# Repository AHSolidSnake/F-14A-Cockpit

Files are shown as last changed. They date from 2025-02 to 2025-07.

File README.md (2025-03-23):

# F-14A-Cockpit
All the STL files for 3D printing a VR focussed F-14A Tomcat cockpit.

Disclaimer: This is designed to work as an artistic license version of a Tomcat which looks "about right" from a few feet away, and feels close enough while playing with a VR headset that the controls are where you reach for them. These files are provided for free to do what you like with and generally if they are uploaded then I have printed them at least once, but YMMV.

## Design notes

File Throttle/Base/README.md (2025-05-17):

# Throttle Base

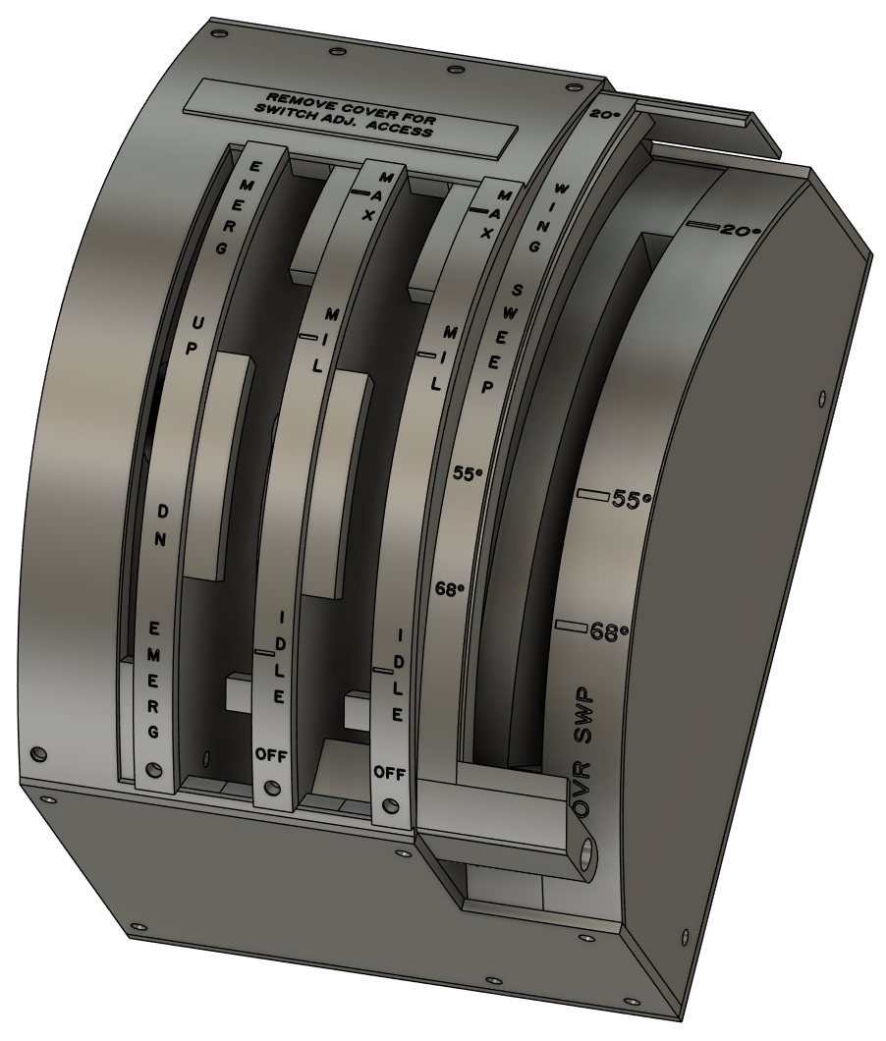
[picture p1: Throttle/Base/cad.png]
CAD Example


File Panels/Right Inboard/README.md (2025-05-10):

# Right Inboard 

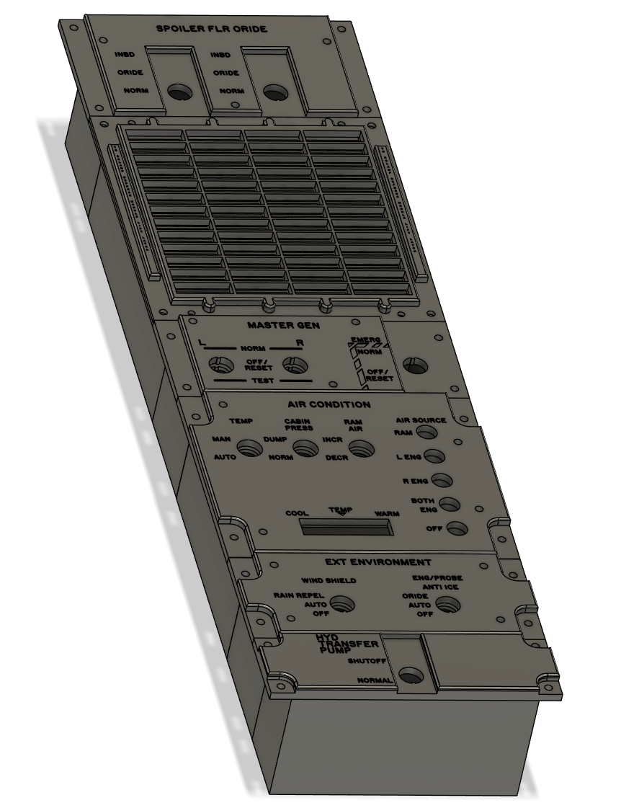
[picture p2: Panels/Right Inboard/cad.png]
CAD Example


## BoM

### Spoiler Override

- 12mm Toggle On-Off x1 [T8013](https://www.aliexpress.com/item/1005001315963290.html)
- Switch Cover [RED](https://www.aliexpress.com/item/1005006832895893.html)

### Caution and Warning

- 4mm LED holders x45 
- Yellow LED x35
- Green LED x10 
- 130mm x 123mm 2mm clear acrylic

### Master Generator

- 12mm Toggle On-Off-On x2 [T8014](https://www.aliexpress.com/item/1005001315963290.html)
- 12mm Toggle On-Off x1 [T8013](https://www.aliexpress.com/item/1005001315963290.html)

### Air Condition

- 12mm Toggle On-Off x3 [T8013](https://www.aliexpress.com/item/1005001315963290.html)
- Piano Switches - Credit to user Hagen at DCS Forums [LINK](https://forum.dcs.world/topic/141193-f-14-cockpit-and-instrument-dimensions/page/38/)

### External Environment

- 12mm Toggle On-Off-On x2 [T8014](https://www.aliexpress.com/item/1005001315963290.html)

### Hydraulic Transfer Pump

- 12mm Toggle On-Off x1 [T8013](https://www.aliexpress.com/item/1005001315963290.html)
- Switch Cover [RED](https://www.aliexpress.com/item/1005006832895893.html)

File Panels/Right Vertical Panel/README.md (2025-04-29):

# Right Vertical Panel

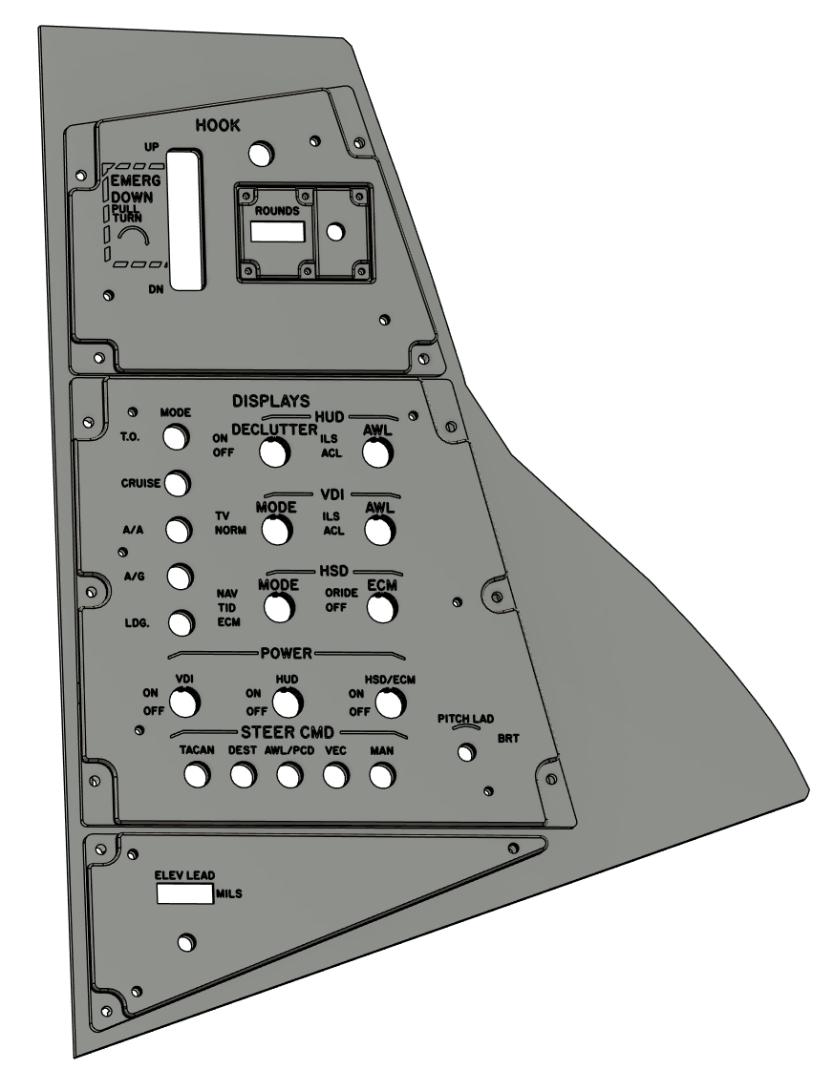
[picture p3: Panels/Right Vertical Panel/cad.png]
CAD Example


## BoM

### Hook Panel

- Rotary Encoder
- 2mm clear acrylic window 24mm x 11mm
- Hook Lever - [Tek Creations F-18 Mk3](https://tekcreations.space/product/f18-hornet-hook-lever-mkii/)

### PDCP

- 12mm Toggle On-Off x9 [T8013](https://www.aliexpress.com/item/1005001315963290.html)
- Piano Switches - Credit to user Hagen at DCS Forums [LINK](https://forum.dcs.world/topic/141193-f-14-cockpit-and-instrument-dimensions/page/38/)
- Rotary Encoder

### Gun Elevation

- Rotary Encoder
- Tally Counter (Non functional) [LINK](https://amzn.eu/d/he2qN3s)
- 2mm clear acrylic window 25mm x 11mm

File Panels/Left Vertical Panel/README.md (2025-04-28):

# Left Vertical Panel

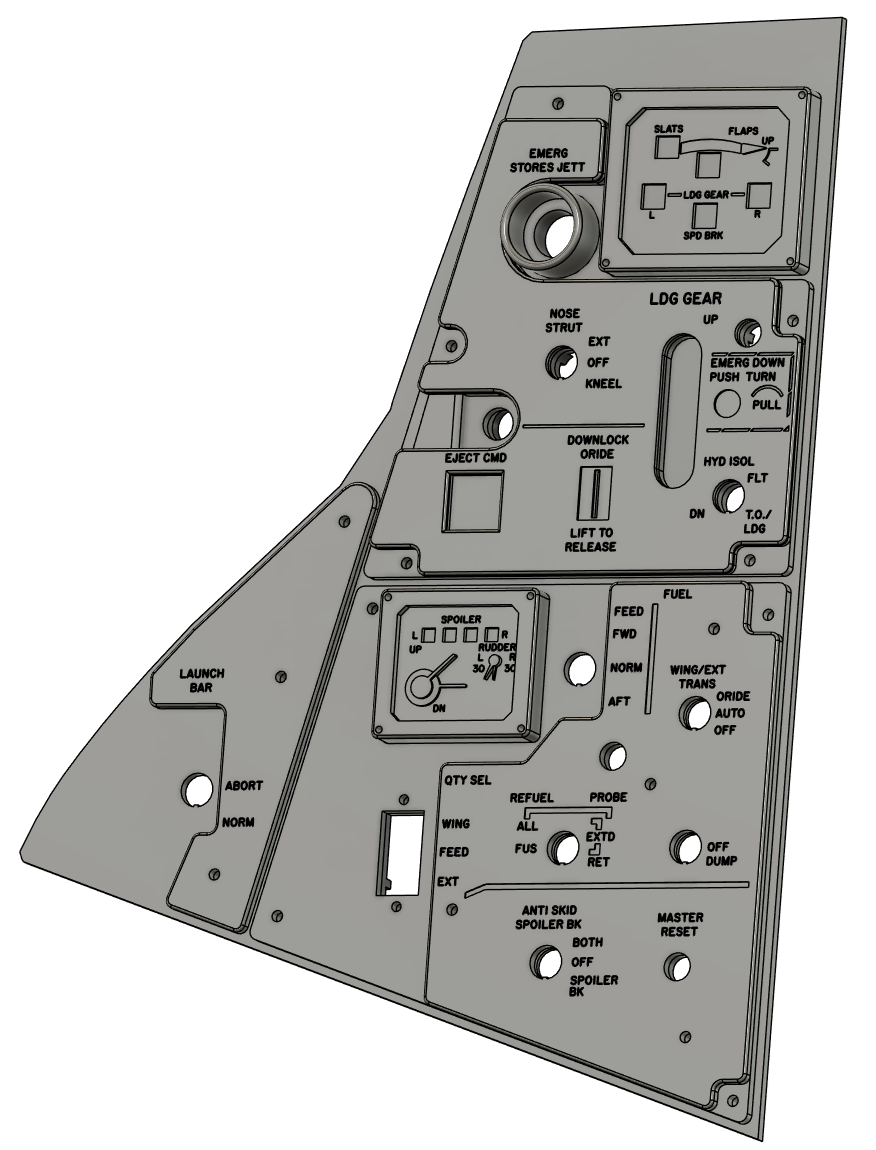
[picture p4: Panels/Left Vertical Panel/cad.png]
CAD Example


Trim and Gear panels are non-functional and for display purposes only.

## BoM

### Gear Panel

- Emergency JETT - 16mm red push button [LINK](https://amzn.eu/d/eFpsVKk)

- Brakes - 10mm Push Pull Switch [LINK](https://www.aliexpress.com/item/1005007343801175.html)

- Gear Lever - [Tek Creations F-18 Mk3](https://tekcreations.space/product/f18-hornet-hook-lever-mkii/)

### Fuel Panel

- Master Reset - 12mm Push Button Switch [R13-85](https://www.aliexpress.com/item/1042107033.html)

- Fuel Trans, Refuel, Spoiler Brakes - 3x On-Off-On 12mm Toggle [T8014](https://www.aliexpress.com/item/1005001315963290.html)

- Fuel Dump - On-Off 12mm Toggle  [T8013](https://www.aliexpress.com/item/1005001315963290.html)

- Quantity Switch - (On) Off (On) Rocker [NKK SW-3007A](https://www.aliexpress.com/item/1005008354400323.html)

### Launch Bar

- Launch Abort - On-Off 12mm Toggle  [T8013](https://www.aliexpress.com/item/1005001315963290.html)

- Launch Abort Cover - [LINK](https://www.aliexpress.com/item/1005006832895893.html)

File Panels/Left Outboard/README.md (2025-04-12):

# Left Outboard

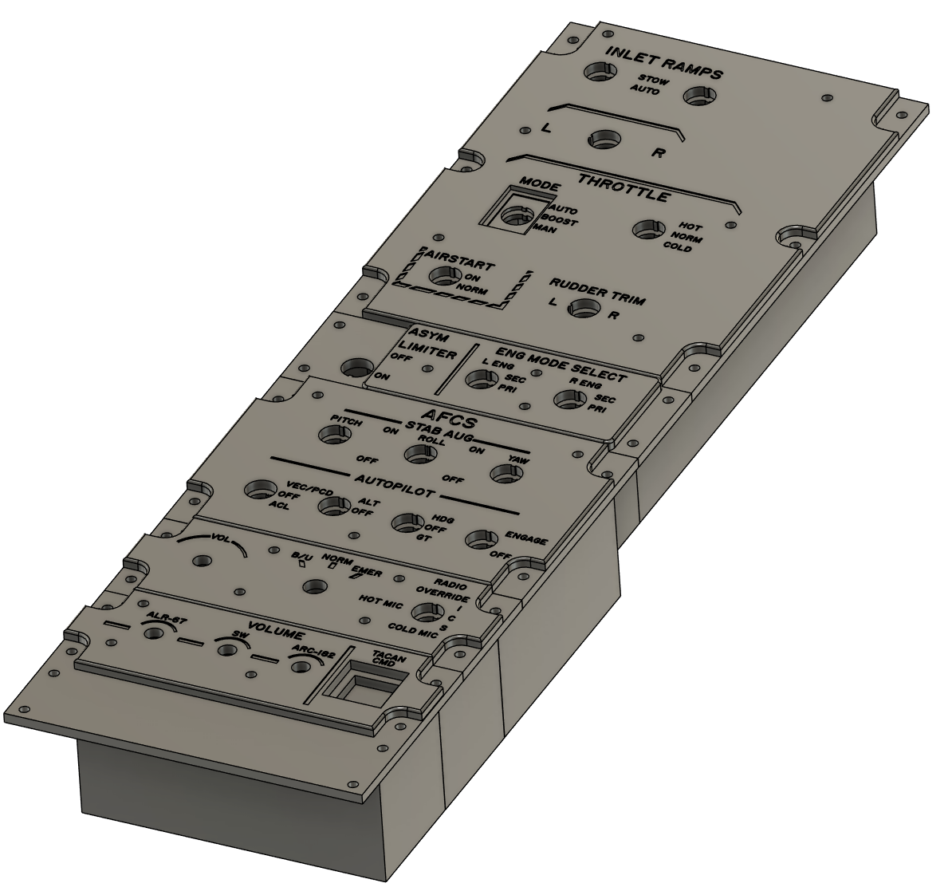
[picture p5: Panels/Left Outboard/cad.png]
CAD Example


## BoM

### Throttle

- 12mm Toggle On-Off x3 [T8013](https://www.aliexpress.com/item/1005001315963290.html)
- 12mm Toggle On-Off-On x2 [T8014](https://www.aliexpress.com/item/1005001315963290.html)
- 12mm Toggle (On)-Off-(On) 

### Engine Asymmetric Limiter 

- 12mm Toggle On-Off x3 [T8013](https://www.aliexpress.com/item/1005001315963290.html)
- Switch Cover [RED](https://www.aliexpress.com/item/1005006832895893.html)

### AFCS

- 12mm Toggle On-Off x5 [T8013](https://www.aliexpress.com/item/1005001315963290.html)
- 12mm Toggle On-Off-On x2 [T8014](https://www.aliexpress.com/item/1005001315963290.html)

### ICS

- 12mm Toggle On-Off-On x1 [T8014](https://www.aliexpress.com/item/1005001315963290.html)
- 3 Way Rotary
- Potentiometer

### Volumes

- 3x Potentiometer 
- Lit Square Korry Style Switche x 1 [DIY737](https://www.737diysim.com/product-page/custom-dual-colour-korry-replica)

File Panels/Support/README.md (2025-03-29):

# Structure

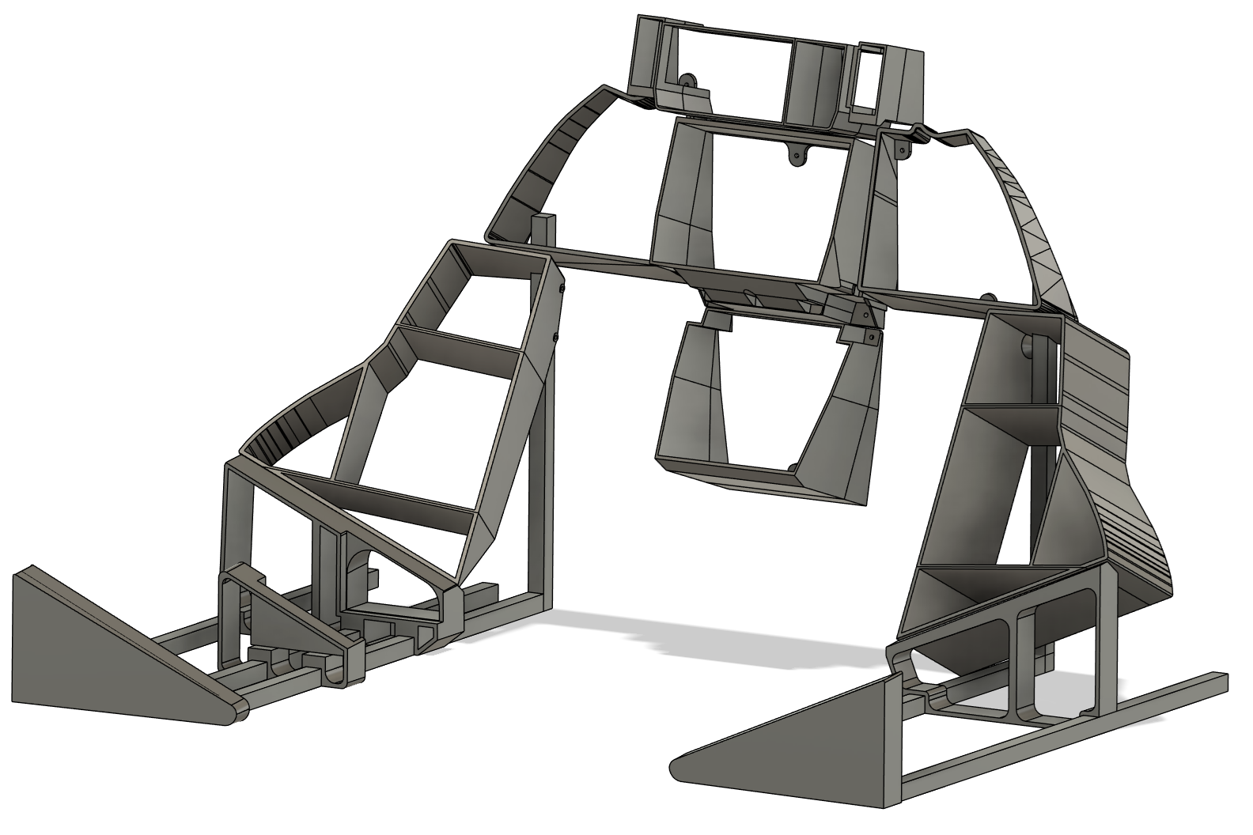
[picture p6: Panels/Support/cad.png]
CAD Example


## BoM

- 20x20 Aluminium Extrusion

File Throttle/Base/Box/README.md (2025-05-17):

# Box / Outer Case

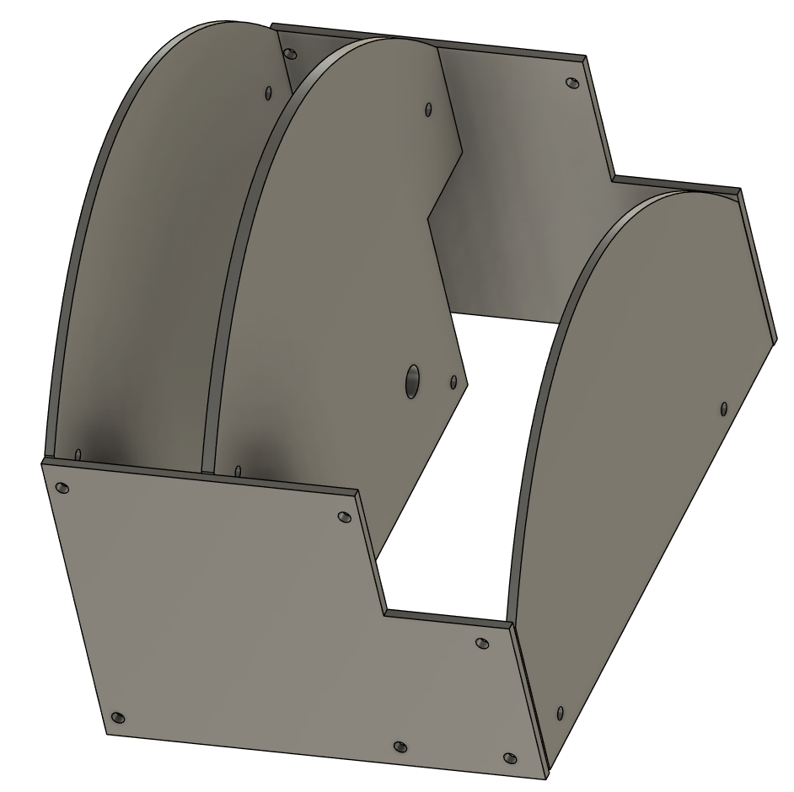
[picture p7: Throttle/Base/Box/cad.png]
CAD Example


Either 3D print STL files or laser cut acrylic/aluminium to build casing.

Back/Front/Left/Right 	- 3mm thickness
Center 			- 4mm thickness

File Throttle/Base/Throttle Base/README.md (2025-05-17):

# Throttle Base

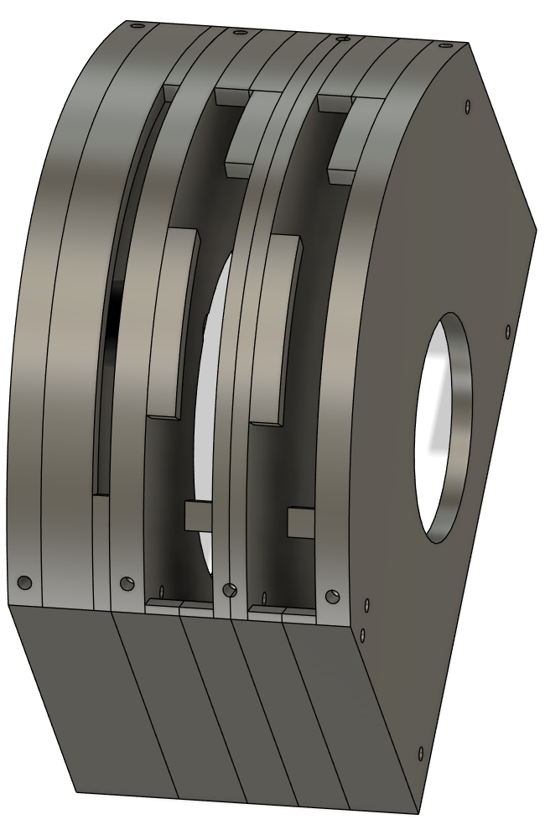
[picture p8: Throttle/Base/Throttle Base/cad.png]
CAD Example


From left to right

- (Box/Left Plate)
- Flaps Box
- Throttle Levers Left Plate
- Throttle Levers Middle Left
- (Box/Center Plate)
- Throttle Levers Middle Right
- Throttle Levers Right Plate
- (Wingsweep)

## BoM

- 2x Rotary Damper in Left/Right Plates [ACE Controls FDT-70](https://www.acecontrols.co.uk/uk/products/motion-control/rotary-dampers/fdt/fdt/fdt-70.html)

- 2x Hall Effect Potentiometer in Center Plate [TT6127](https://www.ttelectronics.com/Products/Passive-Components/Potentiometers/6127)

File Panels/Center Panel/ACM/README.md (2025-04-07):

# ACM Panel

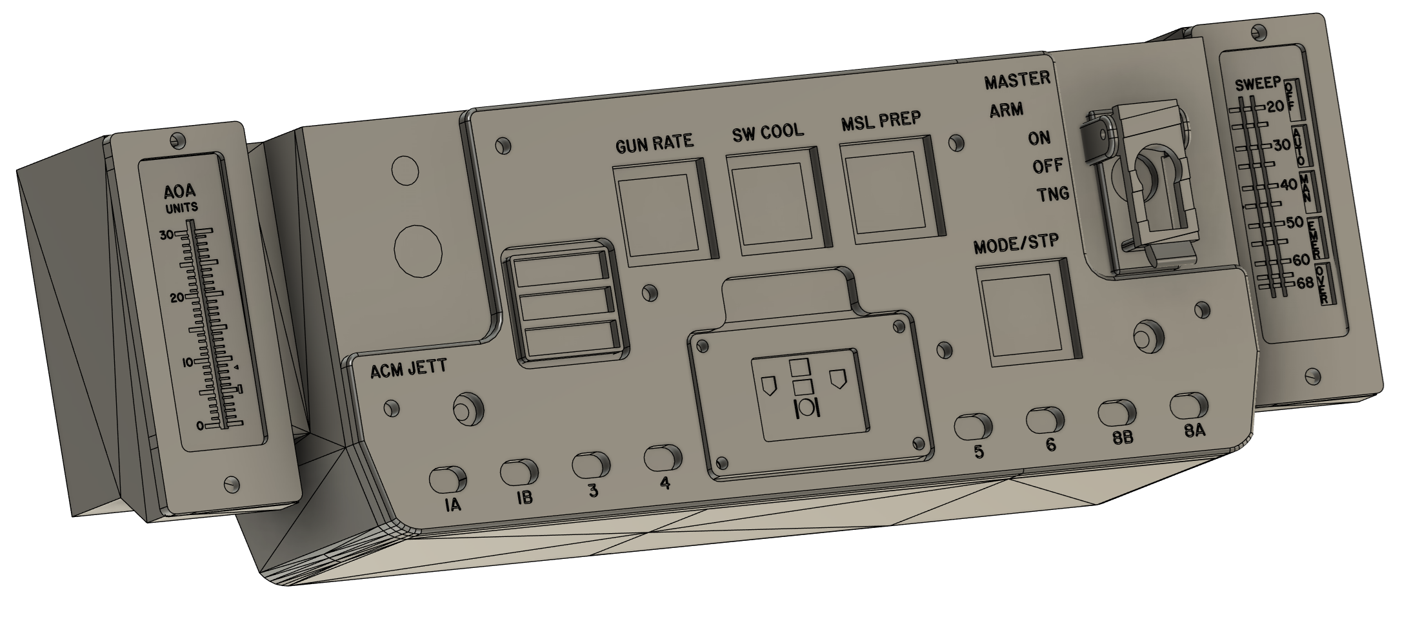
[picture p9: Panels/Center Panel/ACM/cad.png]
CAD Example


AoA / Wing Sweep / Turn-Slip Indicator are non-functional and for display purposes only.

## BoM

- Master Arm - 12mm Locking Toggle Switch [NKK S-7AL](https://www.aliexpress.com/item/1005007970489843.html)

- Lit Square Korry Style Switches x 4 [DIY737](https://www.737diysim.com/product-page/custom-dual-colour-korry-replica)

- ACM JETT - 12mm Push Button Switch [R13-85](https://www.aliexpress.com/item/1042107033.html)

- ACM JETT - Mini Toggle

- ACM JETT Cover - LA Sooner Shapeways (No Link)

- 71mm x 24mm Clear Acrylic Window AoA/Wing Sweep

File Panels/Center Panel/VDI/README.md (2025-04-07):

# VDI

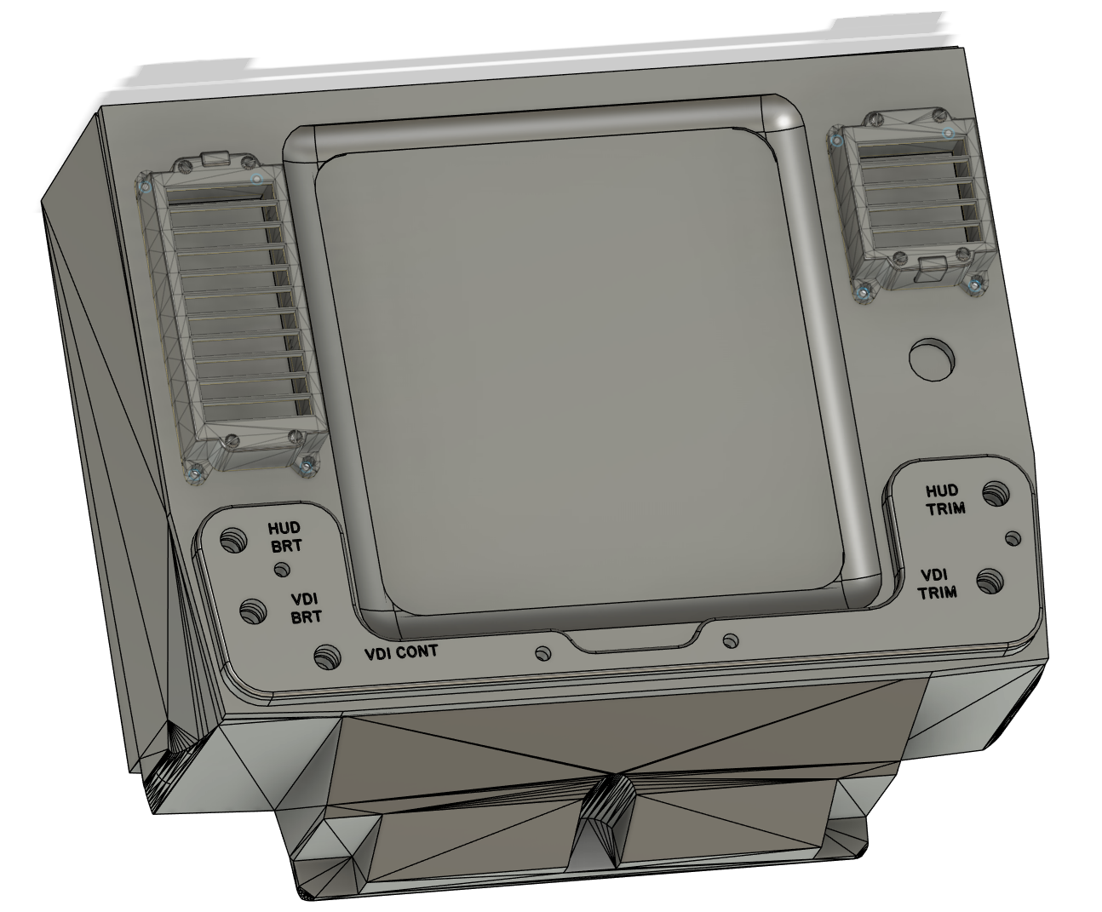
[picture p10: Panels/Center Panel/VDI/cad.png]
CAD Example


## BoM

- Filter - Push Pull Switch [LINK](https://www.aliexpress.com/item/1005007343801175.html?spm=a2g0o.order_list.order_list_main.10.4b8e1802ASbqHO)

- Long 13mm Potentiometers [LINK](https://amzn.eu/d/cVvK1kD)

- 17mm Potentiometer Knobs [LINK](https://amzn.eu/d/1eI4sv0)

- 8" Screen [LINK](https://www.aliexpress.com/item/1005007225502307.html)

- 144mm x 138mm Tinted Acrylic

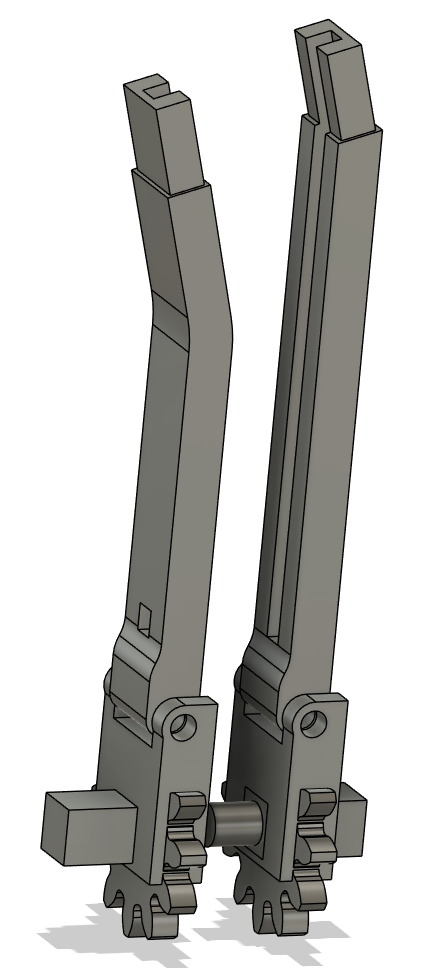
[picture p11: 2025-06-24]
Throttle/Grips/Levers/cad.png

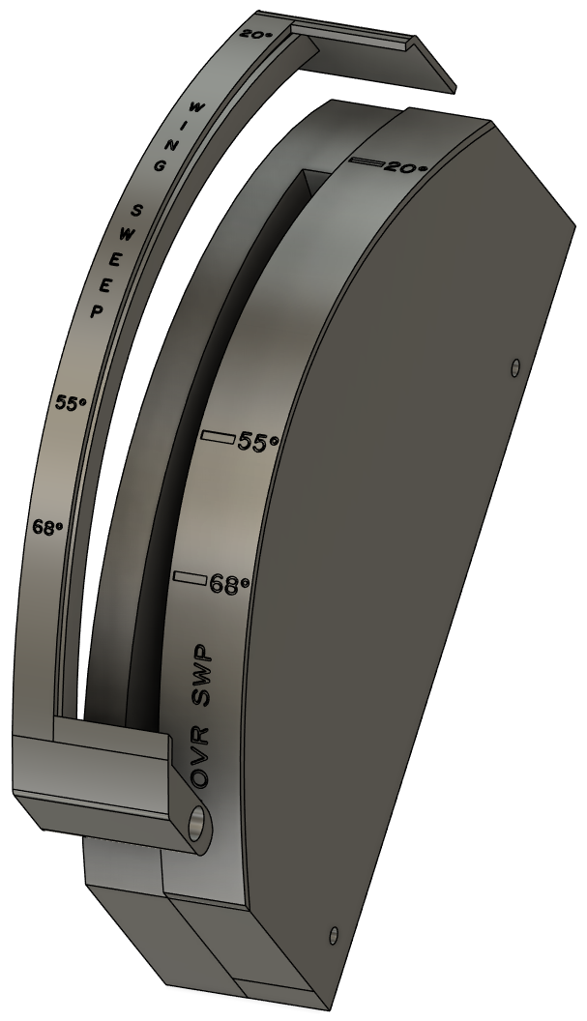
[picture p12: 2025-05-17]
Throttle/Base/Wing Sweep/cad.png

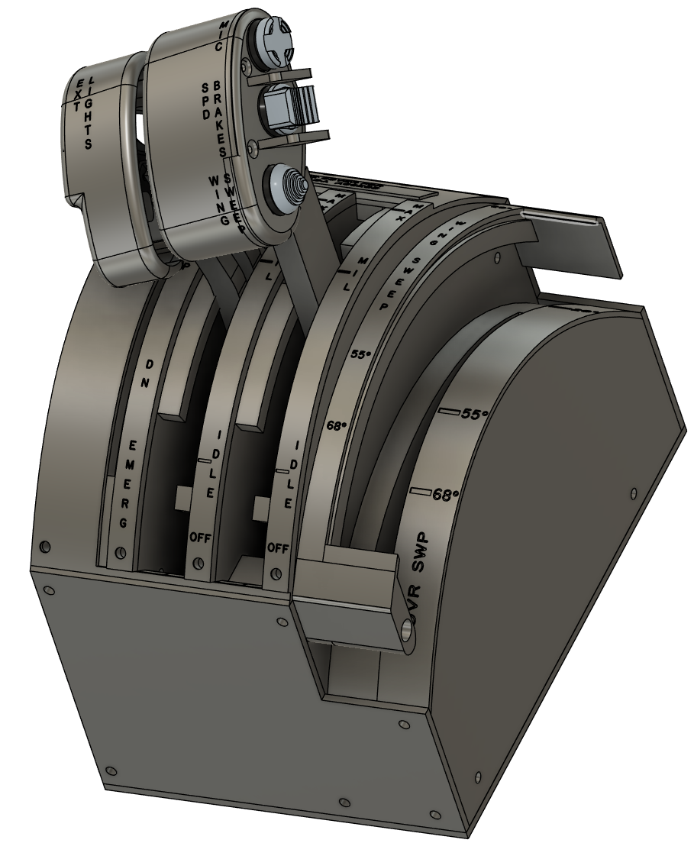
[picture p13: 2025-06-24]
Throttle/cad.png

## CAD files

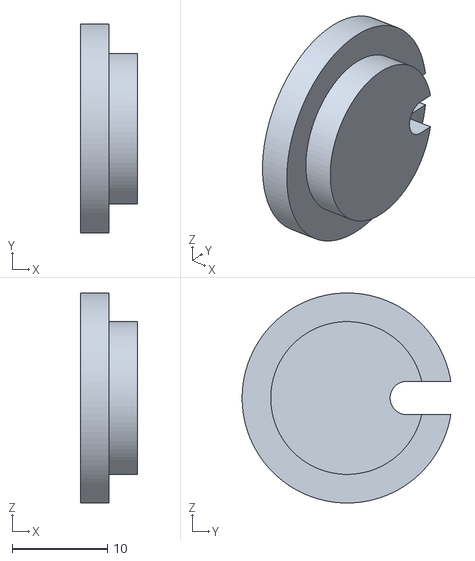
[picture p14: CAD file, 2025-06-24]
Extras/16mm USB Plug x1.stl
6.00 x 21.9 x 22.0

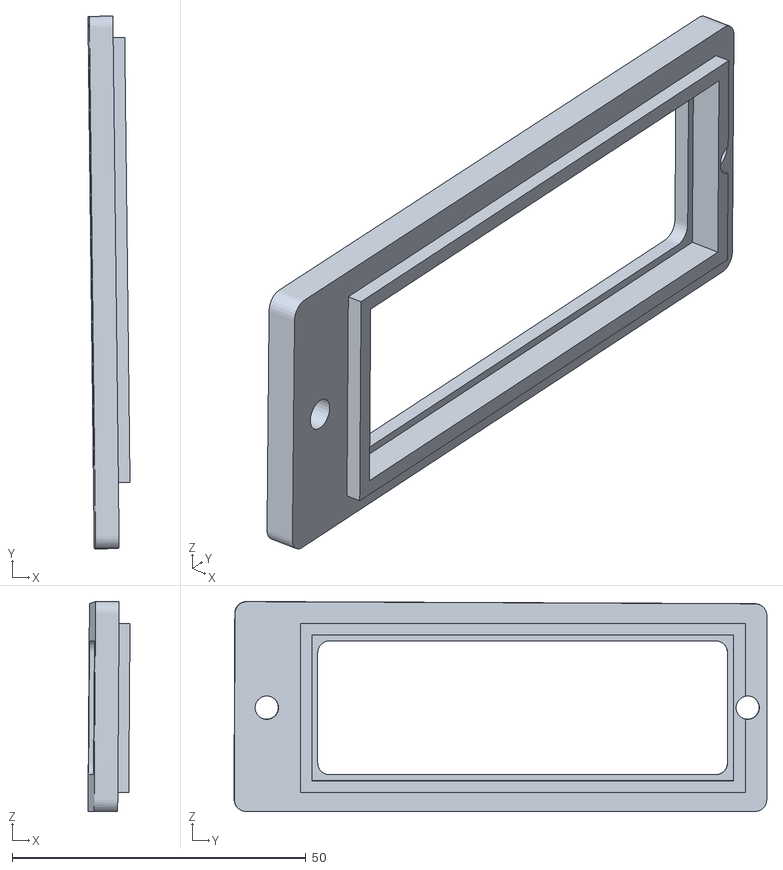
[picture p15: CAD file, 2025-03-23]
Panels/Center Panel/ACM/ACM - AoA - Wing Position - Covers.stl
7.16 x 90.7 x 35.8

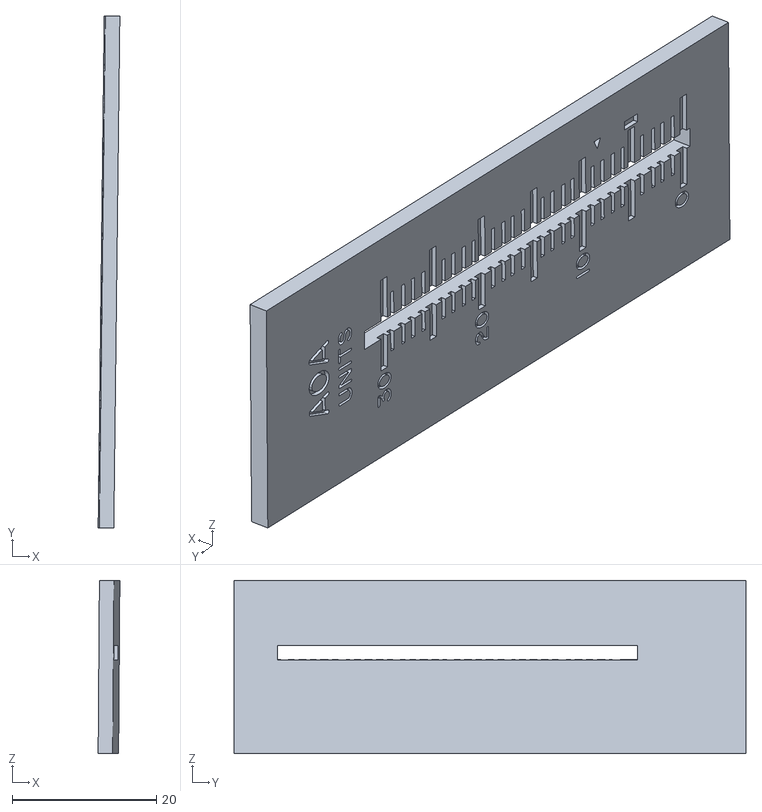
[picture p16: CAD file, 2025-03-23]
Panels/Center Panel/ACM/ACM - AoA/ACM - AoA - Engrave - Top.stl
3.02 x 71.0 x 24.0

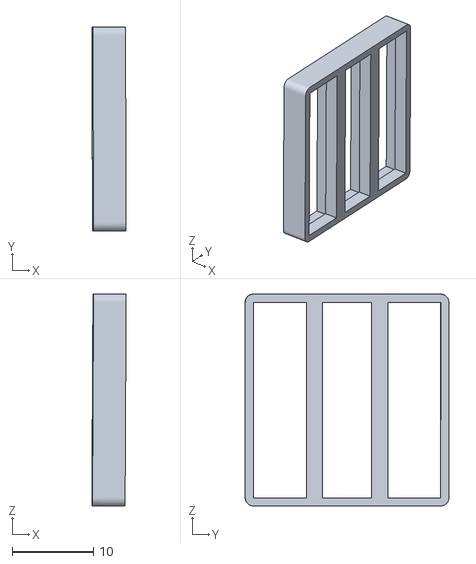
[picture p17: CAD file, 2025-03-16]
Panels/Center Panel/ACM/ACM - Lights/ACM - Lights - Box.stl
4.22 x 25.0 x 26.0

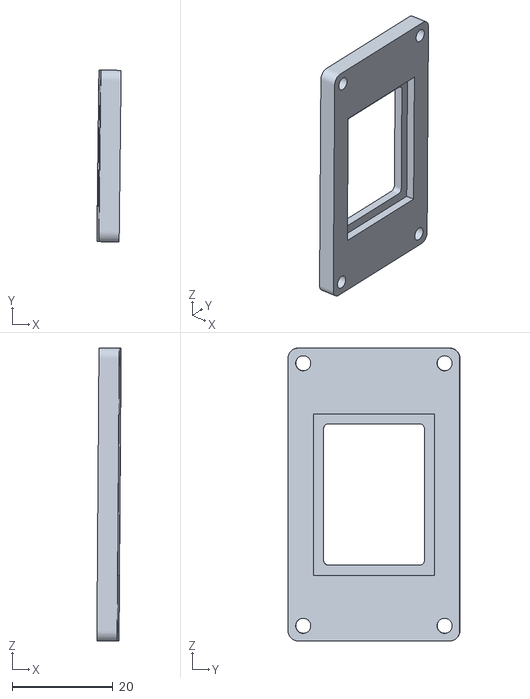
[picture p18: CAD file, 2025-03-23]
Panels/Center Panel/ACM/ACM - Turn Slip/ACM - Turn Slip - Cover.stl
4.81 x 34.0 x 58.0

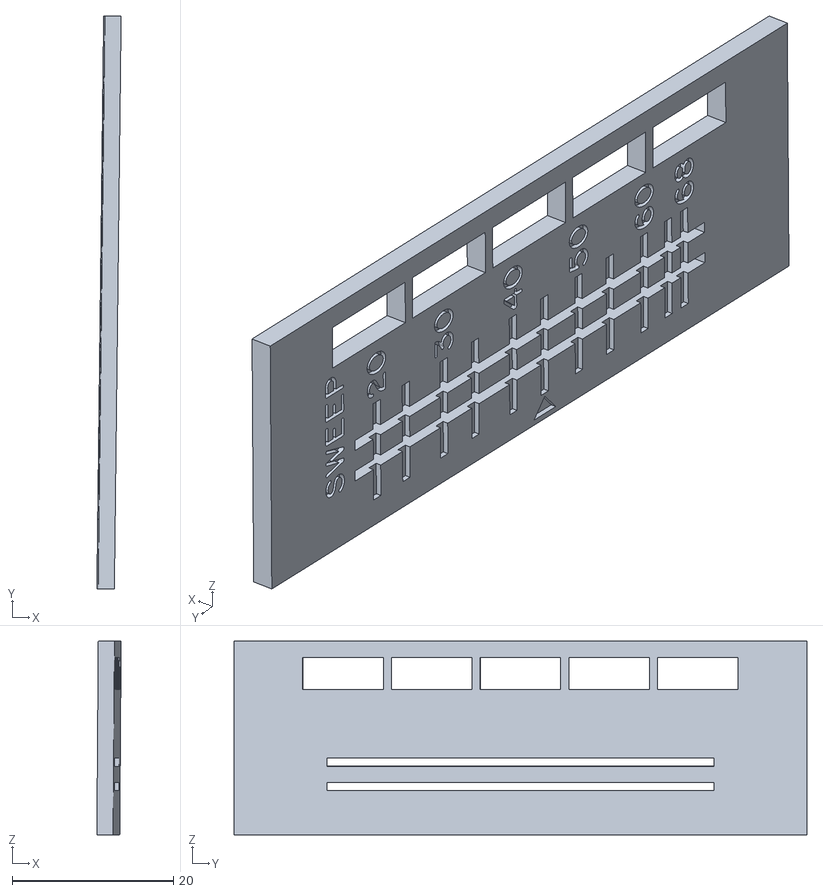
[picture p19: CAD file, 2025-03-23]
Panels/Center Panel/ACM/ACM - Wing Sweep/ACM - Wing Sweep - Engrave - Top.stl
3.02 x 71.0 x 24.0

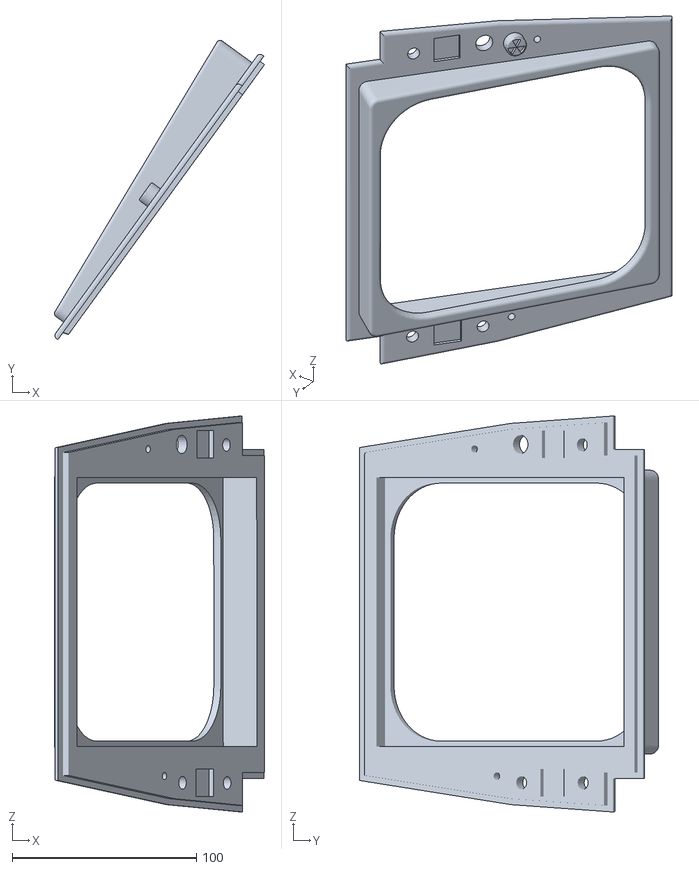
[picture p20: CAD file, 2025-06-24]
Panels/Center Panel/HSD/HSD - Top Panel.stl
114.0 x 162.4 x 214.9

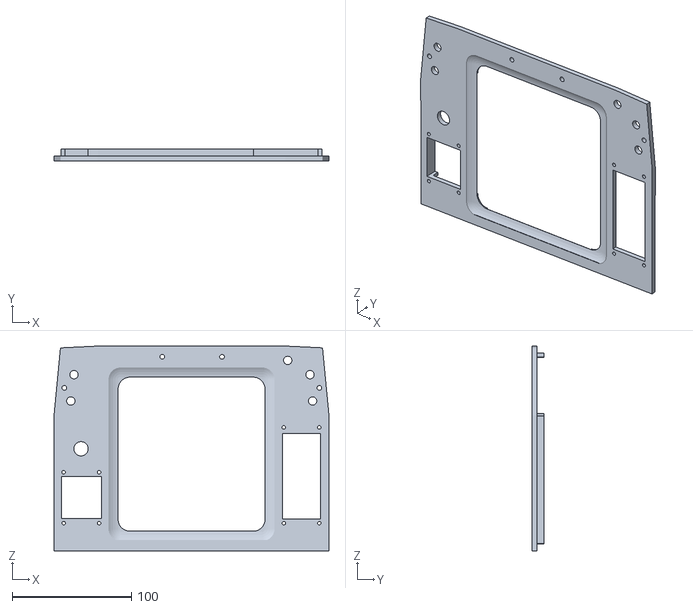
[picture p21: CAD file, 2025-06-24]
Panels/Center Panel/VDI/VDI - Back Panel.stl
230.2 x 10.0 x 171.5

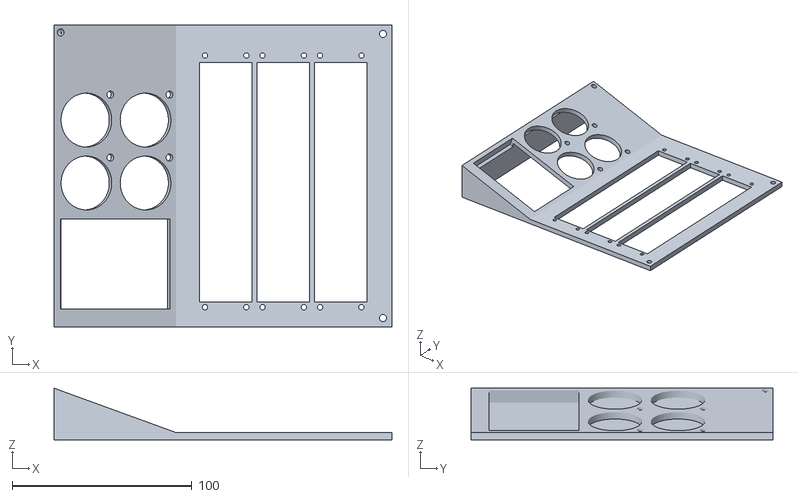
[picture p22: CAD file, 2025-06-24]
Panels/Knee Panels/Left Support.stl
188.0 x 168.0 x 28.7

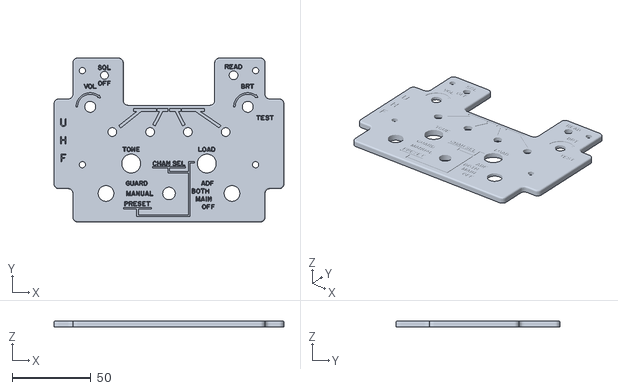
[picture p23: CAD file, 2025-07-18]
Panels/Left Inboard/ARC-159/ARC-159 - Top Panel.stl
146.1 x 104.1 x 4.00

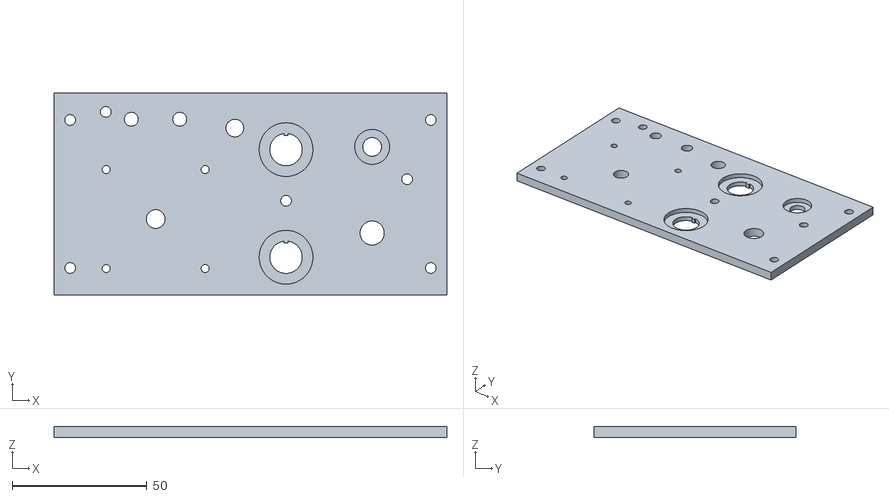
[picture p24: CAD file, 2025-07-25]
Panels/Left Inboard/TACAN/TACAN - Bottom Panel.stl
146.1 x 75.0 x 4.00

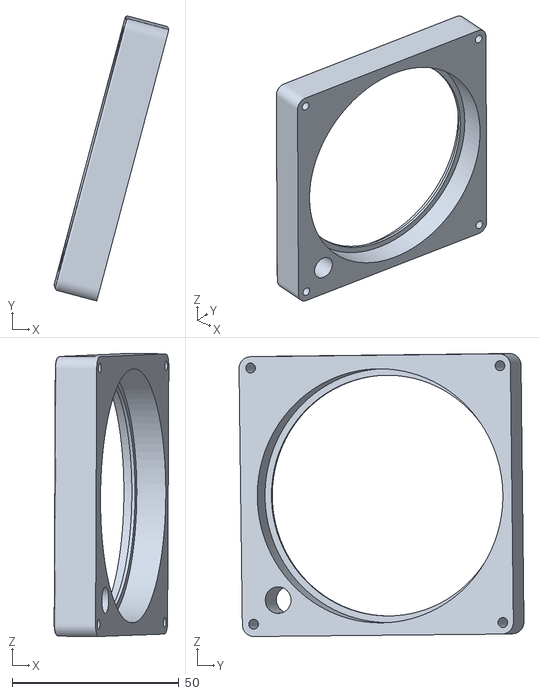
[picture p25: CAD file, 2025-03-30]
Panels/Left Instrument Panel/ALT.stl
34.4 x 85.4 x 84.8

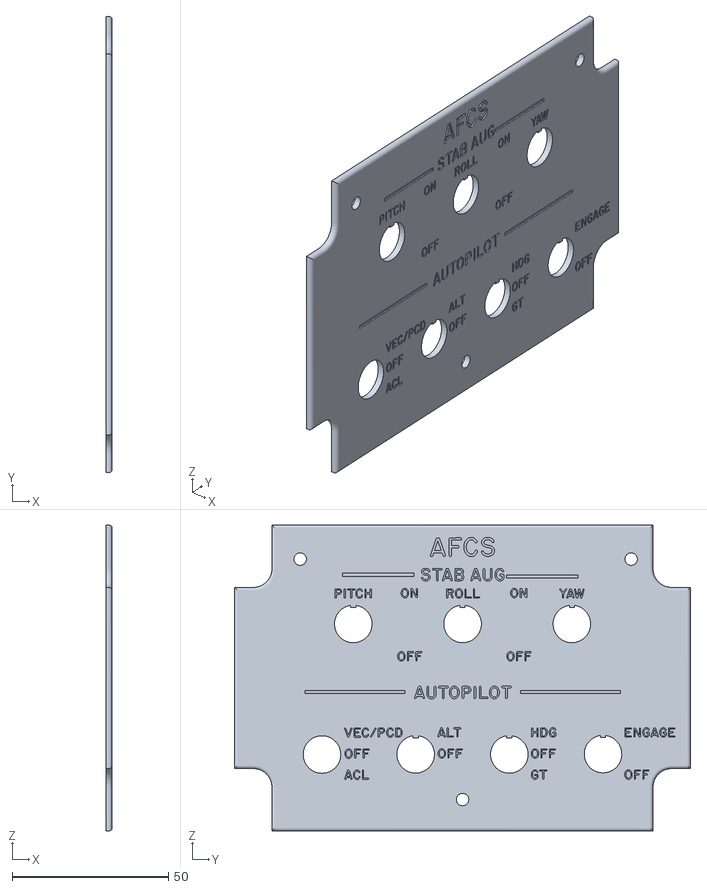
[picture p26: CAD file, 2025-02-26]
Panels/Left Outboard/AFCS/AFCS - Top Panel - Engrave.stl
2.00 x 146.0 x 98.0

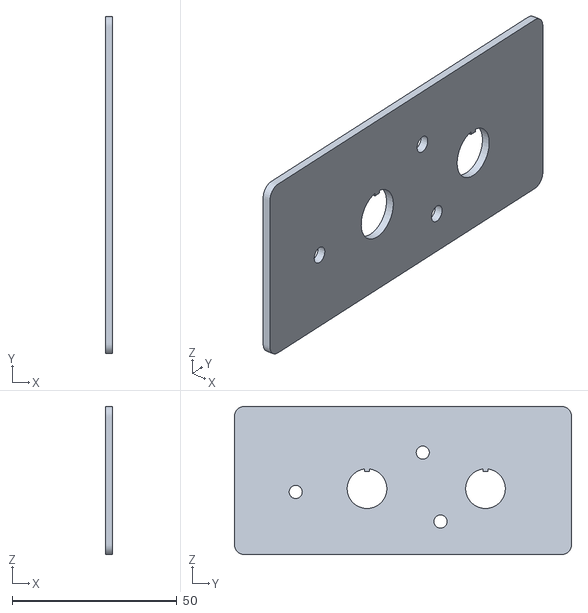
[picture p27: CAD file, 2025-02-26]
Panels/Left Outboard/ASYM LIMIT/ASYM LIMIT - Top Panel - Light.stl
2.00 x 102.4 x 45.0

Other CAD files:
Panels/Left Outboard/Back Spacer.stl
Panels/Left Outboard/ICS/ICS - Top Panel - Light.stl
Panels/Left Outboard/THROTTLE/THROTTLE - Top Panel - Engrave.stl
Panels/Left Outboard/VOLUME/VOLUME - Top Panel - Engrave.stl
Extras/BBI-32 Plate.stl
Extras/Drill Guide.stl
Extras/USB Plug x2.stl
Extras/USB Plug.stl
Panels/Center Panel/ACM/ACM - AoA/ACM - AoA - Back Plate.stl
Panels/Center Panel/ACM/ACM - Back Panel.stl
Panels/Center Panel/ACM/ACM - Lights/ACM - Lights - Back Panel.stl
Panels/Center Panel/ACM/ACM - Lights/ACM - Lights - Collision Light.stl
Panels/Center Panel/ACM/ACM - Lights/ACM - Lights - Hot Trig Light.stl
Panels/Center Panel/ACM/ACM - Lights/ACM - Lights - SEAM Light.stl
Panels/Center Panel/ACM/ACM - Lights/ACM - Lights - Top Panel.stl
Panels/Center Panel/ACM/ACM - Master Arm - Bracket.stl
Panels/Center Panel/ACM/ACM - Master Arm - Cover.stl
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

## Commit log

2025-02-09 Left outboard lower box
    [AFCS - Box.stl, ASYM Limit - Box.stl, ICS - Box.stl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]
2025-02-23 organise, add throttle topper
    [AFCS - Bottom Panel.stl, AFCS - Box.stl, ASYM Limit - Bottom Panel.stl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]
2025-02-23 Add remaining left panel tops
    [AFCS - Top Panel - Engrave.stl, AFCS - Top Panel - Light.stl, ASYM LIMIT - Top Panel - Engrave.stl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]
2025-02-23 Add ACM top plate
    [ACM - Top Panel - Engrave.stl, ACM - Top Panel - Light.stl]
2025-02-26 Update engraved parts to minimum 2mm thick. Update light panels to match max thick of 4mm
    [AFCS - Top Panel - Engrave.stl, AFCS - Top Panel - Light.stl, ASYM LIMIT - Top Panel - Engrave.stl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]
2025-03-04 Add spoilers panel top plates
    [SPOILERS - Top Panel - Engrave.stl, SPOILERS - Top Panel - Light.stl]
2025-03-09 Add ACM panels, PDCP, and ELEV LEAD
    [ACM - Back Panel.stl, ELEV LEAD - Bottom Panel.stl, ELEV LEAD - Top Panel - Engrave.stl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]
2025-03-15 Add HOOK panel, update backplate, add JETT cover
    [HOOK - Bottom Panel.stl, HOOK - Rounds Counter - Base.stl, HOOK - Rounds Counter - Top.stl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]
2025-03-15 Revert RVP changes, add LVP
    [JETT Cover.stl, LVP - Back Plate.stl, RVP - Back Plate.stl]
2025-03-15 LVP Panels
    [FUEL - Bottom Panel.stl, FUEL - Top Panel - Engrave.stl, FUEL - Top Panel - Light.stl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]
2025-03-16 Add ACM Panel lights, update LVP for fuel toggle switch
    [ACM - Lights - Back Panel.stl, ACM - Lights - Box.stl, ACM - Lights - Collision Light.stl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]
2025-03-16 VDI tweaks, break top into light layer and engrave layer
    [VDI - Cover Plate - Engrave.stl, VDI - Cover Plate - Light.stl, VDI - Cover Plate.stl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]
2025-03-22 More LVP panel tweaks from prototype prints
    [FUEL - Bottom Panel.stl, FUEL - Top Panel - Engrave.stl, FUEL - Top Panel - Light.stl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]
2025-03-23 Add and amend various panels
    - Add AoA and wing position side panels for ACM panel
    - Add ACM panel lights box
    - Add ACM turn / slip indicator
    - Tweak LVP fuel panel
    - Add trim instrument to fuel panel
    - Add C&W right inboard panel (WIP)
    - Tweak spoilers for right inboard panel
    [ACM - AoA - Back Plate.stl, ACM - AoA - Engrave - Top.stl, ACM - AoA - Wing Position - Covers.stl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]
2025-03-23 LVP BoM links
2025-03-23 LVP BoM update
2025-03-29 Tweak VDI and add back box. update readme
    [VDI - Back Panel.stl, VDI - Box - Bottom.stl, VDI - Box - Top.stl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]
2025-03-29 Add docs for structure, organise
    [Left Back Wedge.stl, Left Front Wedge.stl, Left Middle Wedge.stl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]
2025-03-29 Tweak VDI front panel
    [VDI - Back Panel.stl, VDI - Top Panel - Engrave.stl, VDI - Top Panel - Light.stl]
2025-03-30 HYD TRANS panel
    [HYD TRANS - Bottom Panel.stl, HYD TRANS - Top Panel - Left.stl, HYD TRANS - Top Panel - Right.stl]
2025-03-30 Tweaks to right inboard side panels
    [AIRCON - Bottom Panel.stl, AIRCON - Box.stl, AIRCON - Top Panel - Engrave.stl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]
2025-03-30 Shuffle support back boxes, add instrument panels
    [ACM - Box - Bottom Left.stl, ACM - Box - Bottom Right.stl, ACM - Box - Top Left.stl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]
2025-03-30 Tweak to fit switch cover
    [MASTERGEN - Bottom Panel.stl]
2025-03-30 Right outboard panels, tweak HSD knob placements
    [C&W - Top Panel.stl, COMPASS - Bottom Panel.stl, COMPASS - Box.stl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]
2025-04-07 Tweaks
    C&W light box holes adjusted
    Spoilers panel shape tweaks
    PDCP updated with slots to allow piano key switches through
    [C&W - Light Box.stl, Drill Guide.stl, PDCP - Bottom Panel.stl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]
2025-04-07 Separate out elev lead panel, tweak aircon panel for piano key inserts
    [AIRCON - Bottom Panel.stl, AIRCON - Top Panel - Engrave.stl, AIRCON - Top Panel - Light.stl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]
2025-04-11 Panel tweaks
    [AIRCON - Box.stl, ELEV LEAD - Bottom Panel.stl, ELEV LEAD - Top Panel - Engrave.stl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]
2025-04-13 Redo most boxes to 30mm, redo entire EXT ENV panel
    [C&W - Box.stl, EXTENV - Bottom Panel.stl, EXTENV - Box.stl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]
2025-04-17 Amend right inboard boxes after redesign of right back support.
    [EXTENV - Box.stl, HYD TRANS - Box.stl, MASTERGEN - Box.stl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]
2025-04-28 Update gear back/engrave/light panels to size for tekcreations hook lever
    [AIRCON - Bottom Panel.stl, AIRCON - Box.stl, GEAR - Bottom Panel.stl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]
2025-04-28 Add tekcreations to BoM for LVP, fix folder name for VDI in support folder
    [VDI - Box - Bottom.stl, VDI - Box - Top.stl]
2025-04-29 Update GEAR/HOOK panels for tekcreations levers
    [GEAR - Bottom Panel.stl, GEAR - Top Panel - Engrave.stl, HOOK - Bottom Panel.stl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]
2025-04-29 Update BoM
2025-05-10 Adjust spacings on HSD inputs, add engraved cutouts.
    [HSD - Top Panel - Left Engrave.stl, HSD - Top Panel - Right Engrave.stl, HSD - Top Panel.stl]
2025-05-10 Add cutout to C&W box for light board, allows space for acrylic insert
    [C&W - Box.stl]
2025-05-17 Add v1 of throttle box and levers base
    [Bottom Plate.step, Bottom Plate.stl, Center Plate.step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]
2025-05-17 Add wing sweep v1
    [Mechanism.stl, Throttle Levers - Center Plate.stl, Throttle Levers - Middle Left.stl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]
2025-06-24 Add Throttle, update support for side panels to fit
    [Back Plate Mount.stl, Cog.stl, Flaps Box.stl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]
2025-06-24 Update wing sweep to fit new box
    [Mechanism.stl, Wing Sweep Box.stl]
2025-06-24 General updates
    [16mm USB Plug x1.stl, AIRCON - Bottom Panel.stl, AIRCON - Wheel.stl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]
2025-06-24 Add canopy controls to right sidewall
    [CANOPY - Box.stl, CANOPY - Mouse Mount.stl, CANOPY - Panel.stl]
2025-07-18 Add UHF box/panel
    [ARC-159 - Bottom Panel.stl, ARC-159 - Box.stl, ARC-159 - Freq Chart.stl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]
2025-07-25 Start TACAN box
    [Back Spacer.stl, TACAN - Bottom Panel.stl, TACAN - Box.stl]
